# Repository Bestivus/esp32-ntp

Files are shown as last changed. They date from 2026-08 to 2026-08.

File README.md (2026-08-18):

## About this fork

This is a fork of [dniminenn/esp32-ntp](https://github.com/dniminenn/esp32-ntp) - a genuinely
excellent piece of engineering, and huge thanks to dniminenn for open-sourcing it. Everything below
this section is the upstream project as-is; here's what changed while bringing it up on my own
hardware.

An earlier version of this fork carried its own ESP-IDF v6.0.2 build fixes and two Kconfig bug
fixes (timezone, display), submitted upstream as PRs. Upstream has since landed its own rewrite -
a first-party W5500 driver replacing the vendored `ioLibrary_Driver`, and an NVS-backed settings
system replacing direct Kconfig reads - which fixes both of those problems natively and makes the
old patches moot. This branch is rebased onto that current upstream code rather than carrying
now-obsolete fixes forward.

- **Dropped the forked `ioLibrary_Driver` submodule.** This fork previously carried a patched
  submodule solely to fix a `recv()` bug where the non-blocking-mode check fired before the
  data-available check, so a non-blocking TCP socket could never actually read data. Upstream's
  new `w5500_drv` fixes this natively, so the fork and the patch are both gone.
- **3D-printed enclosure** ([PR #3](https://github.com/dniminenn/esp32-ntp/pull/3), see
  [`hardware/enclosure/`](hardware/enclosure/)): a two-piece, magnet-held case sized for this
  exact build (D1 Mini ESP32 + W5500 + SparkFun MAX-M10S GPS), STEP and STL included.
- **MQTT status publishing with Home Assistant discovery** (`components/mqtt_publish/`, kept in
  this fork only): publishes GPS lock, stratum, offset, jitter, and diagnostics to an MQTT broker
  with HA auto-discovery. Re-implemented from scratch as a hand-rolled, zero-dependency MQTT 3.1.1
  wire codec running on upstream's `w5500_drv`, since the previous implementation leaned on
  Paho MQTT-C code pulled from the now-dropped `ioLibrary_Driver`. Still a non-blocking,
  tick-driven state machine polled from the NTP task's housekeeping slot, at most one socket call
  per tick, so it can never delay a PPS capture or an NTP reply.
- **`sdkconfig.defaults`** instead of a committed full `sdkconfig`: lists this fork's build-time
  differences from upstream's defaults individually (no display attached, `-O2` build, the
  FreeRTOS tick-rate fix), rather than a full local config snapshot that would carry this
  machine's network settings and credentials into the repo.

The full technical write-up for the original v6.0.2 migration - root causes, debugging process,
everything found and fixed on the code this fork has since moved on from - is in
[`CLAUDE.md`](CLAUDE.md), kept as history.

---

# esp32-ntp: a GPS-disciplined Stratum 1 NTP server for the ESP32

**Writeup:** [Building a GPS stratum 1 NTP server on an ESP32](https://dnim.dev/blog/esp32-stratum-1-ntp)

An ESP32 plus a cheap GPS module, serving Stratum 1 NTP over Ethernet (WIZnet W5500) or
Wi-Fi. PPS edges are captured by the MCPWM peripheral in silicon and packet arrival is
timestamped off the W5500 interrupt, so neither the discipline nor the served timestamps
depend on when a poll loop noticed.

Configuration lives in flash and is edited from a page the device serves itself, so a
deployed clock needs no rebuild and no serial cable. See [Configuration](#configuration).

## What it does

- **Stratum 1 from GPS + PPS.** No internet or upstream server once the GPS has a fix.
- **Hardware timestamping both ways.** MCPWM capture for PPS (12.5 ns resolution at
  80 MHz), W5500 `INTn` capture for NTP arrival.
- **Interleaved mode (RFC 9769).** Clients that ask for it get the measured transmit time
  of the previous reply rather than a predicted one. Invisible to clients that do not.
- **Ethernet or Wi-Fi**, switchable at runtime. The Wi-Fi path compiles out on parts with
  no radio.
- **Settings in flash, edited from a browser**, with a permanent lock for deployment and a
  recovery path if a setting locks you out.
- **Prometheus metrics** at `GET /metrics`.
- **Self-healing:** task watchdog reboots on a hang, and a W5500 health check restarts the
  device if the network chip wedges.
- **Optional MAX7219 LED display.**

## Accuracy

Measured against independent GPS references on the same LAN. Two figures matter and they
are different things:

| | |
|---|---|
| Internal discipline (against its own PPS) | single-digit ns offset, 7 to 11 ns PPS jitter |
| Served time (what a client actually sees) | tens of us, dominated by the network path |

The gap between those two is not the clock. It is the W5500 at 100 Mbit and whatever sits
between the board and the client. A gigabit observer one switch away measured this
firmware at -11.2 us before calibration and within about 100 ns after, with roughly 3 us of
that figure attributable to the 100 Mbit to gigabit speed transition rather than to the
board.

Independent cross-checks: an Intel i210 plus NEO-M9N PTP grandmaster, measuring the ESP32
one routed hop away with its own NIC hardware timestamping, saw about 60 us of offset and
10 to 25 us of per-sample jitter. Separately, in a four-clock ensemble (two NIC-PHC clocks,
a BeagleBone PRU clock and this ESP32), three chrony observers each running full source
selection accept the ESP32 as a truechimer against the other three.

Your numbers depend on your GPS, your antenna, your wiring and your network. The limit is
almost always one of those rather than the ESP32.

## Hardware

<p align="center">
  ESP32 stratum-1 NTP signal wiring: u-blox NEO-6M GPS (NMEA over UART, PPS into GPIO19 captured by MCPWM), and the WIZnet W5500 over SPI with INTn on GPIO34 for hardware RX timestamping. The two hardware-timestamped nets, PPS and INTn, are in coral.
</p>

- **MCU:** the original ESP32 (IDF target `esp32`). 2 MB of flash is enough; the app partition is
  1.9 MB and about half free.

  Three SoC capabilities decide whether a part in the family can run this at all. **MCPWM**, because
  the PPS edge is latched by the capture submodule (capture is not separately gated: ESP-IDF builds
  `mcpwm_cap.c` on `SOC_MCPWM_SUPPORTED` alone, and the capture registers are present in every
  MCPWM-bearing target). **Two usable SPI hosts**, because SPI1 is tied to flash and the W5500 and
  the display each need their own bus, so `SOC_SPI_PERIPH_NUM` has to be 3. WiFi is **not** a
  requirement: the WiFi path compiles itself out on parts without a radio, so those still build and
  simply have no WiFi option. Checked against `soc_caps.h` in ESP-IDF v6.0.2:

  | Target | MCPWM | Usable SPI | WiFi | Verdict |
  |---|---|---|---|---|
  | **ESP32** | yes | 2 | yes | **Supported. The only part built and measured.** |
  | **ESP32-S3** | yes | 2 | yes | **Meets every requirement. Never built here.** |
  | ESP32-C5 | yes | 1 | yes | Only without the display, one bus for the W5500 |
  | ESP32-C6 | yes | 1 | yes | Only without the display, one bus for the W5500 |
  | ESP32-S2 | no | 2 | yes | Impossible, no MCPWM |
  | ESP32-C2 | no | 1 | yes | Impossible, no MCPWM |
  | ESP32-C3 | no | 1 | yes | Impossible, no MCPWM |
  | ESP32-C61 | no | 1 | yes | Impossible, no MCPWM |
  | ESP32-H4 | yes | 2 | no | Builds, Ethernet only, no WiFi option |
  | ESP32-P4 | yes | 2 | no | Builds, but do not: see below |
  | ESP32-H2 | yes | 1 | no | Ethernet only, and no bus left for the display |
  | ESP32-H21 | yes | 1 | no | Ethernet only, and no bus left for the display |

  The four "impossible" rows have no MCPWM and no path forward. Everything else builds from the same
  source with no configuration change; dropping the WiFi path saves about 488 KB of flash where it
  is not available. Anything other than the ESP32 also needs the pin map revisited, which assumes
  ESP32 GPIO numbering and its input-only 34 to 39, and none of them have been built or measured
  here.

  **The ESP32-P4 is a special case: it builds, and you should not.** It is the one part in the
  family whose Ethernet MAC does IEEE 1588v2 hardware timestamping
  (`SOC_EMAC_IEEE1588V2_SUPPORTED`), so the packet timestamps this project works so hard to
  approximate with a W5500 and an interrupt edge are simply available in silicon. Bolting an SPI NIC
  onto a P4 would be strictly worse than using its own MAC, and it is a far more expensive part.
  That gap is also the reason the W5500 exists here at all: the original ESP32 has an EMAC, but
  without 1588 support, so an external MAC whose `INTn` marks arrival is the closest thing to a
  hardware receive timestamp this silicon can offer.
- **Toolchain:** ESP-IDF **v6.0**. Earlier versions predate the split driver components
  (`esp_driver_gpio`, `esp_driver_uart`, `esp_driver_spi`, `esp_driver_mcpwm`) that this project
  requires, so they fail at configure time rather than building something subtly wrong. CI builds
  v6.0.2 from a clean clone.
- **Crystal:** the build pins 40 MHz (`CONFIG_XTAL_FREQ`); some modules ship with a 26 MHz crystal
  instead, and the tell is garbage on the serial console at 115200. If that's your board, change
  `CONFIG_XTAL_FREQ` in `menuconfig`.
- **GPS:** any UART NMEA module with a PPS output (for example NEO-6M, NEO-M8N, or NEO-M9N). PPS
  goes to any GPIO, including input-only pins 34 to 39, because it's captured by the MCPWM
  peripheral.
- **Ethernet (recommended):** WIZnet W5500 on its own SPI bus (HSPI / SPI2 by default, 20 MHz). Its
  `INTn` pin is wired to a GPIO (default GPIO34) for hardware RX timestamping.
- **Display (optional):** up to 4x MAX7219 8x8 matrices on a separate SPI bus (VSPI / SPI3).

Default pins live in `components/config/config.cpp` and can be overridden in `menuconfig`.

## Bill of materials

Street prices for the clone-grade parts most people actually buy (AliExpress / HiLetgo tier, 2026).

| Part | Role | Typical price |
| --- | --- | --- |
| ESP32 DevKitC / WROOM-32 dev board | MCU, MCPWM capture, servo | $5 |
| NEO-6M GPS module + ceramic antenna | GPS fix and the PPS edge | $6 |
| WIZnet W5500 module (RJ45 + magnetics) | wired Ethernet, hardware timestamping | $7 |
| Jumper wires / small perfboard | wiring | $2 |
| 5V USB supply | power (you probably already own one) | $0 to $3 |
| MAX7219 4-in-1 8x8 matrix (optional) | LED display | $6 |

The MCU row means the original ESP32 specifically. See **Hardware** above for which parts in the
family can and cannot run this, and why.

That is about **$20 for the Ethernet Stratum 1**, or roughly **$26 with the display**. The NEO-6M is
the cheapest module with a PPS pin, which is what makes the $20 number real. A NEO-M8N (around $15)
or NEO-M9N (around $30) tightens the PPS and the fix if you want the best version, pushing the build
to roughly $30 to $45.

For comparison, the usual Raspberry Pi Stratum 1 (Pi plus a GPS HAT plus an SD card) lands around
$90 to $130 and still takes its timestamps in software, so it carries Linux scheduling jitter.
Hobby appliances like LeoNTP run about $300, and commercial GPS Stratum 1 units run from $200 into
the thousands.

What makes this build worth its salt rather than just cheap is the part that costs nothing: the
hardware timestamping. MCPWM capture on the PPS edge, W5500 interrupt capture on packet arrival, and
the transmit correction are what put the served jitter under a microsecond, where a naive $20 build
would sit in the milliseconds.

## Build and flash

Prerequisites:
- ESP-IDF v6.0 installed, with `IDF_PATH` set. CI builds v6.0.2; earlier versions do not have the
  split driver components this project requires.

```bash
make build          # idf.py build
make flash          # flash firmware (override speed with: make flash BAUD=230400)
make monitor        # open the serial console
make flash-monitor  # flash then monitor
make menuconfig      # open project configuration
```

Or call `idf.py` directly if you prefer.

> **Tip:** if `make flash` drops mid-transfer ("chip stopped responding") on a flaky USB-serial
> bridge, lower the baud: `make flash BAUD=230400`.

## Configuration

Settings live in flash and are edited from the device's own web page. Everything below can also be
set at build time in `menuconfig`, and those build-time values are what an unconfigured device runs
on, so a freshly flashed board comes up exactly as it always did.

### Settings page

Point a browser at the device on the management port (`8080` by default):

```
http://<device-ip>:8080/
```

Everyday settings are on the page directly: network interface, DHCP or a static address, timezone
(a dropdown of common zones, not a raw POSIX string), the display toggles, the management port, and
an optional password. Wiring settings (every GPIO, SPI host, SPI clock, the GPS UART and the PPS
pin) sit behind an **Advanced** disclosure, because a wrong pin there takes the clock off the
network on the next restart.

Saving writes only the fields you changed and reboots. Values are validated before anything reaches
flash, so an out-of-range pin or a malformed IP is refused with nothing written. Fields marked `*`
need the restart to take effect.

Set a password under **System** unless the network is fully trusted: without one, anyone who can
reach the address can reconfigure or reboot the clock. `/metrics` stays unauthenticated either way
so Prometheus can scrape it.

### Locking it down

Once a clock is configured and in service, the settings page is pure attack surface. Two controls,
in increasing severity:

**Password.** Set one under **System**. It applies to the settings page only; `/metrics` stays open
so Prometheus can scrape without credentials.

**Lock settings permanently.** A fuse. Saving it removes the settings page, `GET /` and
`/config` and `POST /config` all answer `403`, and so does `/factory-reset`, because a reset that
cleared the lock would not be a lock. What survives is NTP on port 123 and `/metrics`, which is
everything a deployed clock actually needs.

It is one way. Nothing over the network undoes it, and neither does the safe-mode path below: safe
mode reads the lock straight out of NVS rather than from the settings it is ignoring, so a bad
config still recovers while the page stays shut. The only way back is physical, erasing the NVS
partition over USB:

```bash
esptool --port /dev/ttyUSB0 erase-region 0x9000 0x6000
```

That takes every stored setting with it and the device returns to build-time defaults.

Locking needs a password set first, which only stops you doing it by accident. Anyone who can
reach an unprotected page owns the device, fuse included.

### If a setting makes the device unreachable

Interrupt startup twice, with the reset button or the power lead. The third boot ignores stored
settings and comes up on the build-time defaults, with a banner on the settings page explaining
why. Your stored values are still in flash and are not touched; saving from that page overwrites
them, and any restart that reaches the network clears the condition on its own.

**Erase stored settings** at the bottom of the page wipes everything back to build-time defaults.

### Settings reference

Every runtime setting, generated from the single table in
`components/config/config_store.c`. **R** means the change takes effect on restart,
**A** means it sits behind the Advanced disclosure on the settings page.

#### Network

| Key | Type | Range | Flags | Setting |
|---|---|---|---|---|
| `net.mode` | choice | `wiznet` / `wifi` | R | Interface. `wifi` is absent on parts with no radio. |
| `net.dhcp` | bool | 0 / 1 | R | Use DHCP. Off means the three fields below are used. |
| `net.ip` | text |  | R | Static IP |
| `net.gw` | text |  | R | Gateway |
| `net.mask` | text |  | R | Netmask |
| `wifi.ssid` | text |  | R | WiFi SSID. Only used when the interface is WiFi. |
| `wifi.pass` | password |  | R | WiFi password |

#### System

| Key | Type | Range | Flags | Setting |
|---|---|---|---|---|
| `sys.tz` | text |  |  | Timezone. Affects the LED display only. NTP always serves UTC. |
| `stats.port` | int | `1`..`65535` | R | Management port. This page and /metrics. |
| `ui.pass` | password |  |  | Management password. Blank leaves this page open to anyone on the network. |
| `ui.lock` | bool | 0 / 1 |  | Lock settings permanently. One way. Saving this removes the settings page for good; only erasing  |

#### Display

| Key | Type | Range | Flags | Setting |
|---|---|---|---|---|
| `disp.en` | bool | 0 / 1 | R | Enable display |
| `disp.glyph` | bool | 0 / 1 |  | Show presync glyph. Marker shown until the GPS locks. |

#### Service

| Key | Type | Range | Flags | Setting |
|---|---|---|---|---|
| `ntp.port` | int | `1`..`65535` | R A | NTP port. 123 is the standard. Clients will not find it anywhere else. |
| `serve.cal` | int | `-100000`..`100000` | A | Serve calibration (us). Subtracted from t2 and t3. Re-derive before changing. |

#### Display wiring

| Key | Type | Range | Flags | Setting |
|---|---|---|---|---|
| `disp.host` | int | `1`..`2` | R A | SPI host. 1 = SPI2, 2 = SPI3. Must differ from the W5500 host. |
| `disp.cs` | int | `-1`..`33` | R A | CS pin |
| `disp.mosi` | int | `-1`..`33` | R A | MOSI pin |
| `disp.sclk` | int | `-1`..`33` | R A | SCLK pin |
| `disp.hz` | int | `100000`..`20000000` | R A | SPI clock (Hz) |
| `disp.ndev` | int | `1`..`16` | R A | Cascaded modules |

#### W5500 wiring

| Key | Type | Range | Flags | Setting |
|---|---|---|---|---|
| `w5.host` | int | `1`..`2` | R A | SPI host. 1 = SPI2, 2 = SPI3. Must differ from the display host. |
| `w5.cs` | int | `-1`..`33` | R A | CS pin |
| `w5.mosi` | int | `-1`..`33` | R A | MOSI pin |
| `w5.miso` | int | `-1`..`39` | R A | MISO pin |
| `w5.sclk` | int | `-1`..`33` | R A | SCLK pin |
| `w5.int` | int | `-1`..`39` | R A | INT pin. Hardware RX timestamping depends on this. |
| `w5.rst` | int | `-1`..`33` | R A | RST pin |
| `w5.hz` | int | `1000000`..`20000000` | R A | SPI clock (Hz). 20 MHz is the proven ceiling on GPIO-matrix pins. Reads corrupt silently above it. |

#### GPS wiring

| Key | Type | Range | Flags | Setting |
|---|---|---|---|---|
| `gps.uart` | int | `0`..`2` | R A | UART port |
| `gps.rx` | int | `-1`..`39` | R A | RX pin (GPS TX) |
| `gps.tx` | int | `-1`..`33` | R A | TX pin |
| `gps.baud` | int | `1200`..`921600` | R A | Baud rate |
| `pps.gpio` | int | `-1`..`39` | R A | PPS pin. Hardware-captured by MCPWM. The whole clock rides on this. |
| `pps.cal` | int | `-1000000`..`1000000` | A | PPS calibration (us) |

`net.mode` is a choice between the W5500 Ethernet path and Wi-Fi STA. `pps.cal` and
`serve.cal` are microsecond trims: `pps.cal` shifts the PPS reference, `serve.cal` is
subtracted from both `t2` and `t3` on the way out. Both default to a value measured on the
reference wiring, so re-derive them if yours differs.

Adding a setting means adding one row to that table. The settings page renders and parses
itself from it, so there is no second place to update.

### Build-time defaults

Project options live under **`esp32-ntp configuration`** in `menuconfig`:

- **Network**
  - **Network interface:** WIZnet W5500 Ethernet or Wi-Fi STA. IP works the same either way
    (DHCP by default, or static IP/gateway/netmask). Hardware transmit-timing correction is used on
    the W5500 path; Wi-Fi uses the same GPS/PPS discipline over the lwIP stack.
  - **Wi-Fi STA:** set **SSID** and **password**.
- **NTP / timezone**
  - `APP_TZ`: POSIX timezone string. Examples:
    - Eastern US: `EST5EDT,M3.2.0,M11.1.0`
    - Central Europe: `CET-1CEST,M3.5.0,M10.5.0/3`
    - UK: `GMT0BST,M3.5.0/1,M10.5.0/2`
    - Atlantic Canada: `AST4ADT,M3.2.0,M11.1.0`
- **SPI / Display**
  - `APP_USE_DISPLAY` and the MAX7219 SPI host/pinout (`APP_SPI_HOST`, `APP_SPI_MOSI_PIN`,
    `APP_SPI_SCLK_PIN`, `APP_CS_PIN`, `APP_MAX_DEVICES`, `APP_SPI_CLOCK_HZ`).

The full set of runtime settings, their valid ranges and their build-time defaults are declared in
one table in `components/config/config_store.c`; adding a setting means adding a row there, and the
settings page renders and parses itself from it.

## Runtime behavior

On boot, `app_main` initializes NVS, brings up the selected network interface (W5500 or Wi-Fi) with
DHCP or static IP, applies the timezone, optionally starts the display task, and then starts GPS/PPS
disciplining, the NTP server, and the stats HTTP server.

**DHCP** on the W5500 path caches the bound lease in flash and reclaims it on the next start
(RFC 2131 INIT-REBOOT) rather than rediscovering from scratch. The address is programmed before the
server confirms it, so a restart while the DHCP server is unreachable still comes back on the last
known-good address instead of a fallback; a NAK hands it straight back and triggers a full
discovery. Only the address, gateway, netmask and server identity are cached, and only rewritten
when those change, so renewals never touch flash. Time from link-up to a usable address is about a
second, since the first frame after link-up is routinely lost while the switch port settles and the
retry backs off 1 s, 2 s, then 4 s rather than waiting 4 s to notice.

**NTP server** (UDP port 123):
- Synthesizes NTP timestamps from the last PPS edge plus a frequency-corrected monotonic timer.
- On the W5500 path: timestamps the request on arrival via the `INTn` interrupt, resolves ARP up
  front, then sends a single reply whose transmit timestamp is pre-corrected for send latency.
- On the Wi-Fi path: a single send through the ESP-IDF lwIP stack.

**Stats / diagnostics HTTP server** (`GET /metrics` on TCP port 8080), Prometheus text format:

| Metric | Meaning |
| --- | --- |
| `ntp_clock_offset_seconds` | Last measured clock offset |
| `ntp_rms_offset_seconds` | Exponentially weighted RMS offset |
| `ntp_frequency_ppm` | Estimated oscillator frequency error |
| `ntp_pps_jitter_seconds` | PPS pulse jitter |
| `ntp_root_dispersion_seconds` | Estimated root dispersion |
| `ntp_gps_lock` | GPS lock state (1 = locked) |
| `ntp_stratum` | NTP stratum (1 when locked) |
| `ntp_uptime_seconds` | Seconds since boot |
| `ntp_requests_total` | NTP requests served |
| `ntp_pps_count` | PPS edges received |
| `ntp_pps_rejects_total` | PPS pulses rejected as outliers |
| `ntp_rx_irq_total` | W5500 RX interrupts captured (hardware arrival edges) |
| `ntp_tx_correction_us` | Self-calibrated transmit-path correction added to `t3` (basic mode only) |
| `ntp_interleaved_served_total` | Replies answered in interleaved mode (RFC 9769) |
| `ntp_reset_reason` | `esp_reset_reason()` of the last boot (1=power-on, 7=task WDT, 8=int WDT, 9=brownout) |
| `ntp_boot_count` | Boots since flash (NVS-persisted, so a jump means it auto-recovered) |
| `ntp_main_loop_beats` | Core-0 main-loop heartbeat |
| `ntp_free_heap_bytes` / `ntp_min_free_heap_bytes` | Current / lowest-ever free heap |
| `ntp_eth_link_up` | W5500 link health |
| `ntp_w5500_version` | W5500 `VERSIONR` (4 = healthy) |

**Self-recovery:** the task watchdog is set to reboot, not just warn, so a firmware hang restarts
the device within seconds. Separately, a W5500 health check restarts the device if the Ethernet chip
or link stays unresponsive. Both are visible after the fact via `ntp_boot_count` and
`ntp_reset_reason`, so you can diagnose a field fault by curling `/metrics` instead of attaching a
cable.

## Code structure

- `main/app_main.cpp`: system bring-up, component wiring, main loop, liveness/boot diagnostics.
- `components/config`: pinout and configuration accessors (`Config::...`).
- `components/gps`: NMEA parsing and PPS discipline (MCPWM hardware capture, PI servo, outlier
  rejection).
- `components/ntp_server`: NTP server over W5500 UDP or Wi-Fi UDP, with hardware RX timestamping and
  transmit-timestamp correction.
- `components/webui`: the HTTP server the device runs on itself. `web_server.cpp` is transport,
  request assembly, routing and auth; `web_metrics.cpp` renders `/metrics`; `web_config.cpp`
  renders and parses the settings page.
- `components/w5500_eth`: W5500 SPI driver, DHCP/static IP, PHY setup, and the link/health watchdog.
- `components/wifi_sta`: Wi-Fi STA with DHCP or static IP.
- `components/w5k`: latency-tuned UDP/TCP wrappers over the W5500 driver for the NTP reply path.
- `components/display`: MAX7219 display driver and rendering.

## License

All code in this repository is released into the public domain under **The Unlicense**, see `LICENSE`.

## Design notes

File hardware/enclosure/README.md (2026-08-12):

# Enclosure

3D-printed two-piece case (magnet-held lid) sized for the "D1 Mini ESP32" board (ESP32-WROOM-32
module, no mounting holes), the W5500 Ethernet breakout, and the SparkFun MAX-M10S GPS module, as
wired up in this project.

Designed in Fusion 360 (Personal), sliced/printed with Orca Slicer.

## Files

- `bottom-case.step` / `bottom-case.stl`
- `top-lid.step` / `top-lid.stl`

`.step` is the editable source (open in any CAD tool to modify); `.stl` is the print-ready mesh.

## Mounting hardware

- **ESP32**: no screws -- held by a friction-fit cradle.
- **GPS module**: 4x M3x6 button head screws.
- **W5500 breakout**: 2x M3x6 button head screws, plus a rear clip molded into the case.

## Magnets

Each half has four embedded holes for 6x2mm magnets (6mm diameter, 2mm thick; eight magnets
total), used to hold the lid closed:

- **Bottom case**: hole diameter 6.2mm, depth 2.4mm, 0.6mm of material remaining above the
  magnet cutout.
- **Top lid**: hole diameter 6.2mm, depth 2.4mm, 0.5mm of material remaining between the lid
  surface and the magnet cutout.

The magnets are embedded during printing, not press-fit afterward: when slicing, insert a pause
in the g-code at the layer where each cutout closes off, drop the magnet in, then resume -- the
print continues over the top of it. Check your slicer's docs for how to add a pause-at-layer/
pause-at-height correctly. Tested on a Bambu Lab X2D without issues, but your mileage may vary --
verify the pause height, the magnet fit tolerance, and consider a non-magnetic nozzle before
committing to a full print.

## License

Unlicense (public domain), matching the rest of this project.

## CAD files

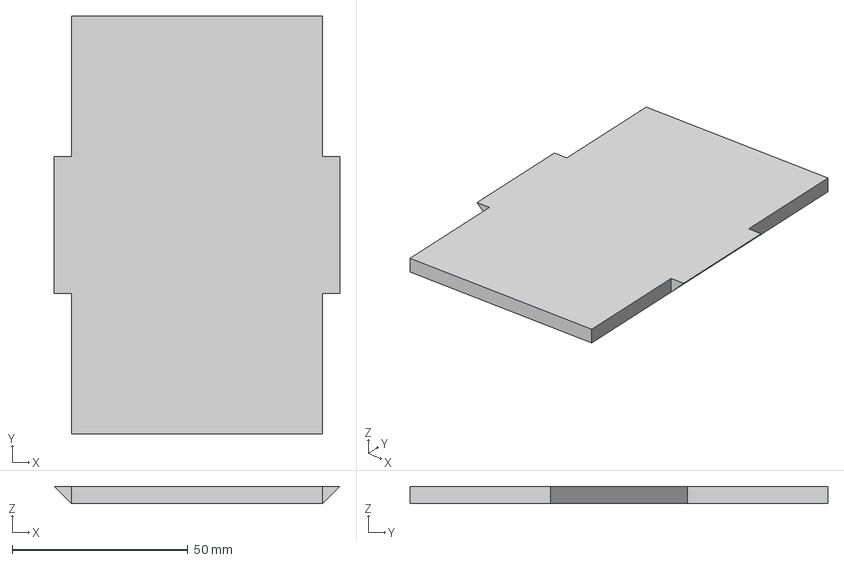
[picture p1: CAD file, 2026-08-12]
hardware/enclosure/top-lid.step
81.3 x 119.0 x 4.90 mm

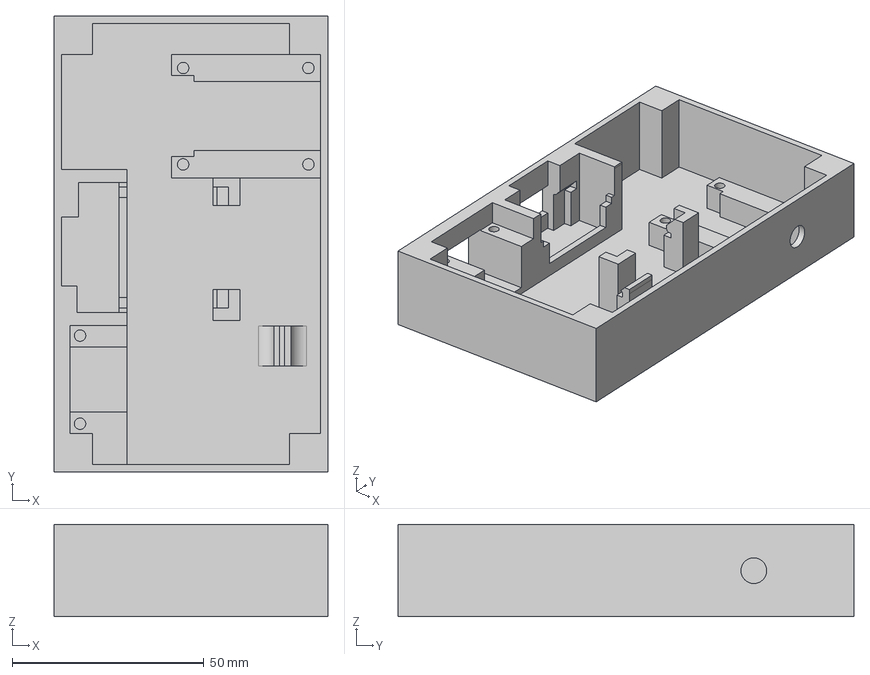
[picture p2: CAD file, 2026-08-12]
hardware/enclosure/bottom-case.step
71.5 x 119.0 x 24.1 mm

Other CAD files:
hardware/enclosure/bottom-case.stl
hardware/enclosure/top-lid.stl

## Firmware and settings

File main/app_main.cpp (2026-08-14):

// SPDX-License-Identifier: Unlicense
// main/app_main.cpp

#include <string.h>
#include <sys/time.h>
#include <time.h>
#include "freertos/FreeRTOS.h"
#include "freertos/task.h"
#include "freertos/semphr.h"
#include "esp_event.h"
#include "esp_log.h"
#include "esp_timer.h"
#include "nvs_flash.h"
#include "nvs.h"
#include "esp_system.h"
#include "esp_netif.h"
#include "driver/uart.h"
#include "esp_pm.h"

#include "config.h"
#include "config_store.h"
#include "display.h"
#include "gps.h"
#include "esp_task_wdt.h"
#include "ntp_server.h"
#include "web_server.h"
#include "w5500_eth.h"
#include "wifi_sta.h"
#include "mqtt_publish.h"

static const char* TAG = "APP";

static Display* g_display = nullptr;
static GpsDiscipline* g_gps = nullptr;
static NtpServer* g_ntpServer = nullptr;
static WebServer* g_web = nullptr;
static W5500Eth* g_ethernet = nullptr;
static WifiSta* g_wifi = nullptr;
static MqttPublisher* g_mqtt = nullptr;
static SemaphoreHandle_t g_displayMutex = nullptr;

// Diagnostics exposed over /metrics (read-only; never on the timekeeping path).
// g_mainLoopBeats advances every core-0 loop iteration — if it stalls between
// two HTTP scrapes the loop is wedged; g_bootCount (persisted in NVS) counts
// boots, so an auto-recovery (watchdog reboot / W5500 restart) is visible
// remotely without attaching a serial monitor.
volatile uint32_t g_mainLoopBeats = 0;
uint32_t g_bootCount = 0;

extern "C" void app_main();

static void display_task(void* arg) {
  int lastDisplayedSecond = -1;
  unsigned long long lastCentiseconds = 0;
  bool wasSynced = false;
  bool glyphShown = false;

  ESP_LOGI(TAG, "Display task started");

  while (true) {
    if (xSemaphoreTake(g_displayMutex, pdMS_TO_TICKS(10))) {
      struct timeval tv;
      gettimeofday(&tv, nullptr);
      struct tm timeinfo;
      localtime_r(&tv.tv_sec, &timeinfo);
      
      unsigned long long centiseconds = (unsigned long long)(esp_timer_get_time() / 10000ULL);
      
      if (centiseconds != lastCentiseconds) {
        int currentSecond = timeinfo.tm_sec;
        bool synced = (g_gps && g_gps->isLocked());
        if (synced && !wasSynced) {
          g_display->clear();
          lastDisplayedSecond = -1;
        }
        
        if (!synced) {
          if (!glyphShown) {   /* static image; redraw only on entering the unsynced state */
            g_display->clear();
            g_display->drawPreSyncGlyph();
            g_display->push();
            glyphShown = true;
          }
        } else {
          glyphShown = false;
          if (currentSecond != lastDisplayedSecond) {
            ESP_LOGD(TAG, "Update display: %02d:%02d:%02d", timeinfo.tm_hour, timeinfo.tm_min, timeinfo.tm_sec);
            g_display->drawTime(timeinfo.tm_hour, timeinfo.tm_min, timeinfo.tm_sec);
            lastDisplayedSecond = currentSecond;
          }
          g_display->drawTopRowFromCentiseconds(centiseconds);
          g_display->push();
        }
        lastCentiseconds = centiseconds;
        wasSynced = synced;
      }
      
      xSemaphoreGive(g_displayMutex);
    }
    vTaskDelay(pdMS_TO_TICKS(1));
  }
}

/* --- Task layout ------------------------------------------------------ */
/* Discipline must outrank serving: a packet flood must never delay a pulse. */
#define PRIO_DISCIPLINE 10
#define PRIO_NTP         7
#define CORE_CLOCK       0
#define CORE_NET         1

static void discipline_task(void* arg) {
  esp_task_wdt_add(nullptr);
  gps_register_task(xTaskGetCurrentTaskHandle());
  for (;;) {
    g_mainLoopBeats = g_mainLoopBeats + 1;              /* liveness, exported over /metrics */
    /*
     * Wake on the PPS capture edge instead of polling for it. The 50 ms timeout
     * is a safety net, not the mechanism: it keeps the holdover checks in
     * GpsDiscipline::loop() running when PPS stops, which is precisely when they
     * matter. NMEA is not affected — it has its own gps_uart task.
     *
     * Note this makes g_mainLoopBeats advance ~20x/s instead of ~500x/s. It is a
     * liveness heartbeat, so what matters is that it still advances.
     */
    gps_wait_for_pps(50);
    if (g_gps) g_gps->loop();
    esp_task_wdt_reset();
  }
}

static void ntp_task(void* arg) {
  esp_task_wdt_add(nullptr);
  unsigned long lastLog = 0;
  unsigned long lastHouse = 0;
  for (;;) {
    /*
     * Wake on the W5500's INTn interrupt. The timeout is a safety net only:
     * a second datagram queued behind one INTn assertion produces no new edge,
     * so a periodic sweep still drains it.
     */
    ntp_wait_for_packet(5 /* ms */);
    if (g_ntpServer) g_ntpServer->loop();

    /*
     * Housekeeping shares this task deliberately. Every W5500 access funnels
     * through shared static frame buffers with no locking anywhere in the
     * driver (w5500_drv.c relies on this), so a second task touching the chip
     * corrupts transfers in flight. Serving from here keeps a single owner
     * without a mutex the hot path would have to acquire per packet.
     */
    /* Time-gated, not sweep-counted: under a burst, packet rate must not drag
     * housekeeping SPI into the reply path. */
    unsigned long nowMs = (unsigned long)(esp_timer_get_time() / 1000ULL);
    if (nowMs - lastHouse >= 20) {
      lastHouse = nowMs;
      if (g_ethernet) g_ethernet->loop();
#if CONFIG_SOC_WIFI_SUPPORTED
      if (g_wifi) g_wifi->loop();
#endif
      if (g_web) g_web->loop();
      if (g_mqtt) g_mqtt->loop();
      unsigned long now = esp_timer_get_time() / 1000000ULL;
      if (now - lastLog >= 60) {
        struct timeval tv2; struct tm ti2;
        gettimeofday(&tv2, nullptr);
        localtime_r(&tv2.tv_sec, &ti2);
        ESP_LOGI(TAG, "Current time: %02d:%02d:%02d", ti2.tm_hour, ti2.tm_min, ti2.tm_sec);
        lastLog = now;
      }
    }
    esp_task_wdt_reset();
  }
}

void app_main() {
  uart_wait_tx_done(static_cast<uart_port_t>(CONFIG_ESP_CONSOLE_UART_NUM), pdMS_TO_TICKS(100));
  vTaskDelay(pdMS_TO_TICKS(500));
  
  uart_flush_input(static_cast<uart_port_t>(CONFIG_ESP_CONSOLE_UART_NUM));
  
  printf("\n\n\n");
  printf("========================================\n");
  printf("       esp32-ntp v1.0\n");
  printf("========================================\n\n");
  
  esp_log_level_set("*", ESP_LOG_INFO);
  esp_log_level_set(TAG, ESP_LOG_INFO);
  esp_log_level_set("spi_master", ESP_LOG_WARN);

  ESP_LOGI(TAG, "=== Clock Starting ===");
  ESP_LOGI(TAG, "Initializing NVS...");
  ESP_ERROR_CHECK(nvs_flash_init());

  // Persisted boot counter — a jump between scrapes reveals an auto-recovery
  // (watchdog reboot or W5500 restart) without needing a serial console.
  {
    nvs_handle_t h;
    if (nvs_open("diag", NVS_READWRITE, &h) == ESP_OK) {
      nvs_get_u32(h, "boots", &g_bootCount);
      g_bootCount++;
      nvs_set_u32(h, "boots", g_bootCount);
      nvs_commit(h);
      nvs_close(h);
    }
    ESP_LOGI(TAG, "Boot count: %u, reset reason: %d", (unsigned)g_bootCount, (int)esp_reset_reason());
  }

  {
    uint8_t attempt = cfg_boot_begin();
    bool safeMode = attempt >= CFG_SAFE_MODE_FAILS;
    ESP_LOGI(TAG, "Start attempt %u since the last start that reached the network",
             (unsigned)attempt);
    Config::init(safeMode);
    if (safeMode) {
      ESP_LOGE(TAG, "SAFE MODE on start attempt %u: build-time defaults, "
                    "stored settings ignored until you save from the config page",
               (unsigned)attempt);
    } else if (cfg_locked()) {
      ESP_LOGW(TAG, "Settings are locked; the config page is disabled");
    } else if (Config::isProvisioned()) {
      ESP_LOGI(TAG, "Using stored settings from NVS");
    } else {
      ESP_LOGI(TAG, "No stored settings, using build-time defaults");
    }
  }

  // Set a reasonable initial time to avoid massive NTP corrections
  struct timeval tv;
  gettimeofday(&tv, nullptr);
  ESP_LOGI(TAG, "Initial system time: %ld seconds (epoch: %ld)", tv.tv_sec, tv.tv_sec);
  
  if (tv.tv_sec < 1577836800LL) {  // Before 2020-01-01
    tv.tv_sec = 1700000000LL;  // Set to 2023-11-15 as reasonable default
    tv.tv_usec = 0;
    settimeofday(&tv, nullptr);
    ESP_LOGI(TAG, "Set initial time to 2023-11-15 to avoid massive NTP corrections");
    
    // Verify the change
    gettimeofday(&tv, nullptr);
    ESP_LOGI(TAG, "New system time: %ld seconds", tv.tv_sec);
  } else {
    ESP_LOGI(TAG, "System time already reasonable: %ld seconds", tv.tv_sec);
  }
  
  // Initialize networking infrastructure first
  ESP_ERROR_CHECK(esp_netif_init());
  ESP_ERROR_CHECK(esp_event_loop_create_default());
  
  esp_err_t err;

  if (Config::getNetworkWiznet()) {
    ESP_LOGI(TAG, "Initializing W5500 Ethernet...");
    g_ethernet = new W5500Eth();
    err = g_ethernet->begin(
      Config::getW5500SpiHost(),
      Config::getW5500MosiPin(),
      Config::getW5500MisoPin(),
      Config::getW5500SclkPin(),
      Config::getW5500CsPin(),
      Config::getW5500IntPin(),
      Config::getW5500RstPin(),
      Config::getW5500SpiHz()  // 20 MHz default; W5500 spec allows far more
    );
    if (err == ESP_OK) {
      ESP_LOGI(TAG, "W5500 initialized, starting Ethernet...");
      g_ethernet->start(Config::getUseStaticIp(), Config::getStaticIp(),
                       Config::getStaticGw(), Config::getStaticNetmask());
    } else {
      ESP_LOGE(TAG, "W5500 initialization failed: %s", esp_err_to_name(err));
      delete g_ethernet;
      g_ethernet = nullptr;
    }
#if CONFIG_SOC_WIFI_SUPPORTED
  } else if (Config::getNetworkWifi()) {
    ESP_LOGI(TAG, "Initializing WiFi STA...");
    g_wifi = new WifiSta();
    err = g_wifi->begin(Config::getWifiSsid(), Config::getWifiPassword(),
                        Config::getUseStaticIp(), Config::getStaticIp(),
                        Config::getStaticGw(), Config::getStaticNetmask());
    if (err == ESP_OK) {
      g_wifi->start();
      ESP_LOGI(TAG, "WiFi STA started, connecting...");
    } else {
      ESP_LOGE(TAG, "WiFi begin failed: %s", esp_err_to_name(err));
      delete g_wifi;
      g_wifi = nullptr;
    }
#endif
  }
  
  ESP_LOGI(TAG, "Applying timezone: %s", Config::getTimezone());
  Config::applyTimezone();

  ESP_LOGI(TAG, "Waiting for network connection...");
  vTaskDelay(pdMS_TO_TICKS(5000));

  {
    uint32_t ip = 0;
    bool up = (g_ethernet && g_ethernet->getIpAddr(ip));
#if CONFIG_SOC_WIFI_SUPPORTED
    up = up || (g_wifi && g_wifi->getIpAddr(ip));
#endif
    if (up) cfg_boot_healthy();
  }

  if (Config::getUseDisplay()) {
    ESP_LOGI(TAG, "Initializing display...");
    g_display = new Display(Config::getSpiHost(), Config::getCsPin(), Config::getMaxDevices(), Config::getSpiClockHz());
    err = g_display->begin();
    if (err == ESP_OK) {
      ESP_LOGI(TAG, "Display initialized successfully");
      g_display->setIntensity(1);
      g_displayMutex = xSemaphoreCreateMutex();
      ESP_LOGI(TAG, "Display mutex created");
    } else {
      ESP_LOGE(TAG, "Display init failed: %d", err);
      delete g_display;
      g_display = nullptr;
    }
  } else {
    ESP_LOGI(TAG, "Display disabled via config");
  }

  // GPS/PPS will discipline time; NTP client not required.

  // Start GPS/PPS disciplining
  g_gps = new GpsDiscipline();
  g_gps->begin(Config::getGpsUartPort(), Config::getGpsUartBaud(), Config::getGpsUartTxPin(), Config::getGpsUartRxPin(), Config::getPpsGpioPin());

  // Start NTP server (passes GPS reference for lock checking)
  // Latch W5500 packet arrival on a second MCPWM capture channel, sharing the
  // 80 MHz counter that timestamps PPS. Must come after gps->begin() (which
  // creates the capture timer) and before the server starts using it. Wired
  // (not wireless) only — lwIP buffers datagrams, so there is no edge to latch.
  if (!Config::getNetworkWifi() && Config::getW5500IntPin() >= 0) {
    esp_err_t rxerr = g_gps->beginRxCapture(Config::getW5500IntPin());
    if (rxerr == ESP_OK)
      ESP_LOGI(TAG, "RX arrival capture armed on GPIO%d (shared PPS timebase)",
               Config::getW5500IntPin());
    else
      ESP_LOGW(TAG, "RX arrival capture unavailable (%s); t2 falls back to the "
                    "GPIO ISR stamp", esp_err_to_name(rxerr));
  }

  g_ntpServer = new NtpServer();
  g_ntpServer->begin(Config::getNtpServerPort(), g_gps);
  if (g_ethernet) {
    // A W5500 register loss closes every hardware socket along with
    // everything else -- NTP's and MQTT's alike; reopen/reset them whenever
    // the ethernet layer rebuilds the chip. W5500Eth has a single callback
    // slot, so both owners are notified from this one registration.
    g_ethernet->onChipReset([](void*) {
      if (g_ntpServer) g_ntpServer->reopenSocket();
      if (g_mqtt) MqttPublisher::chipResetTrampoline(g_mqtt);
    }, nullptr);
  }

  g_web = new WebServer();
  g_web->begin(Config::getStatsPort(), g_gps, g_ntpServer, g_ethernet, g_wifi);

  if (Config::getMqttEnable() && Config::getNetworkWiznet() && g_ethernet) {
    g_mqtt = new MqttPublisher();
    esp_err_t mqttErr = g_mqtt->begin(
      Config::getMqttBrokerIp(), Config::getMqttBrokerPort(),
      Config::getMqttUsername(), Config::getMqttPassword(),
      Config::getMqttClientId(), Config::getMqttNodeId(),
      Config::getMqttPublishIntervalS(),
      g_gps, g_ntpServer, g_ethernet);
    if (mqttErr != ESP_OK) {
      ESP_LOGE(TAG, "MQTT publisher init failed: %s", esp_err_to_name(mqttErr));
      delete g_mqtt;
      g_mqtt = nullptr;
    }
  }
  gettimeofday(&tv, nullptr);
  struct tm timeinfo;
  localtime_r(&tv.tv_sec, &timeinfo);
  
  ESP_LOGI(TAG, "Initial time: %02d:%02d:%02d", timeinfo.tm_hour, timeinfo.tm_min, timeinfo.tm_sec);

  if (g_display) {
    vTaskDelay(pdMS_TO_TICKS(50));
    g_display->clear();
    g_display->drawPreSyncGlyph();
    g_display->push();

    ESP_LOGI(TAG, "Starting display task...");
    xTaskCreatePinnedToCore(display_task, "display_task", 4096, nullptr, 4, nullptr, 1);
  }

  ESP_LOGI(TAG, "Entering main loop...");
  /*
   * Split the old single poll loop into prioritised tasks.
   *
   * The monolithic loop ended in vTaskDelay(1), so a packet waited up to a full
   * tick before being answered — that random latency was the dominant term in
   * served jitter, and it also meant an arrival capture could not be reliably
   * paired with the datagram that produced it. Worse, NTP load and GPS
   * disciplining shared one thread, so traffic could starve the clock.
   *
   * Now: discipline runs at the highest priority on its own core, the NTP
   * server blocks on a notification from the INTn ISR (so it wakes on arrival
   * rather than on a timer), and housekeeping runs lowest. Each task registers
   * with the Task Watchdog, which is already configured to panic — a wedged
   * discipline task now reboots the box instead of serving a frozen clock.
   */
  xTaskCreatePinnedToCore(discipline_task, "discipline", 4096, nullptr,
                          PRIO_DISCIPLINE, nullptr, CORE_CLOCK);
  xTaskCreatePinnedToCore(ntp_task, "ntp_srv", 4096, nullptr,
                          PRIO_NTP, nullptr, CORE_NET);
  ESP_LOGI(TAG, "tasks started: discipline(prio %d core %d) ntp(prio %d core %d)",
           PRIO_DISCIPLINE, CORE_CLOCK, PRIO_NTP, CORE_NET);
  /* app_main returns; the tasks own the system from here. */
}

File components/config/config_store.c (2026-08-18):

// SPDX-License-Identifier: Unlicense

#include "config_store.h"
#include "sdkconfig.h"
#include "nvs.h"
#include "nvs_flash.h"
#include "hal/spi_types.h"
#include "esp_log.h"
#include "esp_attr.h"
#include <string.h>
#include <stdio.h>
#include <stdlib.h>

static const char* TAG = "CFGSTORE";
static const char* NVS_NS = "ntpcfg";

/* Kconfig entries that only exist under one branch of the network choice. */
#ifndef CONFIG_APP_USE_PRESYNC_GLYPH
#define CONFIG_APP_USE_PRESYNC_GLYPH 0
#endif
#ifndef CONFIG_APP_WIFI_SSID
#define CONFIG_APP_WIFI_SSID ""
#endif
#ifndef CONFIG_APP_WIFI_PASSWORD
#define CONFIG_APP_WIFI_PASSWORD ""
#endif
#ifndef CONFIG_APP_STATIC_IP_ADDR
#define CONFIG_APP_STATIC_IP_ADDR "192.168.1.100"
#endif
#ifndef CONFIG_APP_STATIC_GW
#define CONFIG_APP_STATIC_GW "192.168.1.1"
#endif
#ifndef CONFIG_APP_STATIC_NETMASK
#define CONFIG_APP_STATIC_NETMASK "255.255.255.0"
#endif
#ifdef CONFIG_APP_NETWORK_WIFI
#define DEF_NET_MODE 1
#else
#define DEF_NET_MODE 0
#endif
#ifdef CONFIG_APP_USE_STATIC_IP
#define DEF_NET_DHCP 0
#else
#define DEF_NET_DHCP 1
#endif
#ifdef CONFIG_APP_USE_DISPLAY
#define DEF_DISP_EN 1
#else
#define DEF_DISP_EN 0
#endif

#define PIN_OUT -1, 33
#define PIN_IN  -1, 39

#ifdef CONFIG_SOC_WIFI_SUPPORTED
static const char* const kNetModes[] = { "wiznet", "wifi" };
#define NET_MODE_MAX 1
#else
static const char* const kNetModes[] = { "wiznet" };
#define NET_MODE_MAX 0
#endif

static const char* const kTzOpts[] = {
  "UTC0",                                    "UTC",
  "GMT0BST,M3.5.0/1,M10.5.0",                "UK - London",
  "CET-1CEST,M3.5.0,M10.5.0/3",              "Central Europe - Paris, Berlin, Madrid",
  "EET-2EEST,M3.5.0/3,M10.5.0/4",            "Eastern Europe - Athens, Helsinki",
  "<-01>1<+00>,M3.5.0/0,M10.5.0/1",          "Azores",
  "NST3:30NDT,M3.2.0,M11.1.0",               "Canada - Newfoundland",
  "AST4ADT,M3.2.0,M11.1.0",                  "Canada - Atlantic",
  "EST5EDT,M3.2.0,M11.1.0",                  "US/Canada - Eastern",
  "CST6CDT,M3.2.0,M11.1.0",                  "US/Canada - Central",
  "MST7MDT,M3.2.0,M11.1.0",                  "US/Canada - Mountain",
  "MST7",                                    "US - Arizona (no DST)",
  "PST8PDT,M3.2.0,M11.1.0",                  "US/Canada - Pacific",
  "AKST9AKDT,M3.2.0,M11.1.0",                "US - Alaska",
  "HST10",                                   "US - Hawaii (no DST)",
  "<-03>3",                                  "Brazil - Sao Paulo",
  "<-03>3",                                  "Argentina - Buenos Aires",
  "<-06>6",                                  "Mexico - Mexico City",
  "MSK-3",                                   "Russia - Moscow",
  "<+04>-4",                                 "Gulf - Dubai",
  "IST-5:30",                                "India",
  "<+07>-7",                                 "Thailand, Vietnam",
  "CST-8",                                   "China, Singapore, Hong Kong",
  "JST-9",                                   "Japan",
  "KST-9",                                   "Korea",
  "AWST-8",                                  "Australia - Perth",
  "ACST-9:30ACDT,M10.1.0,M4.1.0/3",          "Australia - Adelaide",
  "AEST-10AEDT,M10.1.0,M4.1.0/3",            "Australia - Sydney, Melbourne",
  "AEST-10",                                 "Australia - Brisbane (no DST)",
  "NZST-12NZDT,M9.5.0,M4.1.0/3",             "New Zealand",
  "SAST-2",                                  "South Africa",
  NULL
};

#define PIN_HELP "ESP32 GPIO. 34-39 are input-only."
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

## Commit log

2026-08-04 Skip ARP prime for resolved peer, tighten capture gate
    [ntp_server.cpp, w5k_udp_wrapper.c]
2026-08-04 one SPI transaction per W5500 access on the reply path
2026-08-04 run the CPU at 240 MHz, fix truncated /metrics, recalibrate served offset
    [config.cpp, ntp_server.cpp, w5k_udp_wrapper.c]
2026-08-04 put the reply path in IRAM; scope the SPI counters honestly
2026-08-04 Grow dispersion at frequency-estimate uncertainty, not raw error
    [gps.cpp]
2026-08-12 fix timezone kconfig not being read, guard missing display macro
    Two independent bugs found while bringing this project up on new hardware:
    1. getTimezone() returned a hardcoded literal ("AST4ADT,M3.2.0,M11.1.0")
    instead of reading CONFIG_APP_TZ, even though the Kconfig option for it
    already existed. No menuconfig edit could ever change the timezone.
    2. getUseDisplay() referenced CONFIG_APP_USE_DISPLAY unconditionally. When
    the display is disabled in menuconfig, ESP-IDF does not define that
    macro at all (it is simply absent, not defined to 0), so disabling the
    display in menuconfig broke the build. Guarded with #ifdef, defaulting
    to false when the option is compiled out.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
    [config.cpp]
2026-08-12 add 3d-printable enclosure (step + stl, top lid and bottom case)
    * Add 3D-printable enclosure (STEP + STL, top lid and bottom case)
    Two-piece magnet-held case sized for the D1 Mini ESP32 board, W5500
    breakout, and MAX-M10S GPS module used by this project. Designed in
    Fusion 360, sliced/printed with Orca Slicer.
    Both halves have embedded 6x2mm magnet holes (6.2mm diameter, 2.4mm
    depth) to hold the lid closed without screws -- see
    hardware/enclosure/README.md for the exact clearances above each
    magnet cutout.
    * hardware/enclosure: document mounting screws and correct magnet count (4 per half)
    [bottom-case.step, bottom-case.stl, top-lid.step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]
2026-08-12 sync committed sdkconfig with the board: 240 MHz cpu, 80 MHz flash
2026-08-13 Fix ESP-IDF v6.0 build errors: driver component splits, volatile increments, missing-field-initializer, missing <time.h>, close() collision
    ESP-IDF v6.0 reorganized several driver components (GPIO/UART moved out of
    the generic "driver" component into esp_driver_gpio/esp_driver_uart, only
    reachable via PRIV_REQUIRES from within "driver" itself, not passed to
    dependents) and made several previously-cosmetic warnings into hard errors:
    - components/gps, components/w5500_eth: add esp_driver_gpio /
    esp_driver_uart to REQUIRES so driver/gpio.h and driver/uart.h resolve.
    - components/w5500_eth/w5500_eth.cpp: C++20+ deprecates '++'/'+=' on
    volatile-qualified variables (this project builds with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
    [app_main.cpp, w5500_eth.cpp]
2026-08-13 wire ntp server/port kconfig into config.cpp
2026-08-13 document the fail-loud contract over the reply-path spin
    [w5500_eth.cpp]
2026-08-13 wire display spi kconfig into config.cpp, drop dead ntp port getter
2026-08-13 replace the wiznet iolibrary with a first-party w5500 driver and dhcp client
    [app_main.cpp, ntp_server.cpp, w5500_drv.c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]
2026-08-13 store settings in nvs and add a management ui on the stats server
    [partitions.csv]
2026-08-13 fix the boot-fail counter and let the management password be removed
    [app_main.cpp, config_store.c]
2026-08-13 pin every setting on first save so a value matching the build default still persists
2026-08-13 declare 2mb flash so the partition table still fits small esp32 modules
    [partitions.csv]
2026-08-13 declare the real idf floor, 4.1 never had the split driver components
2026-08-13 let the settings page be fused off for good, and say so in the readme
2026-08-13 Re-apply fork-specific docs onto upstream's current main
    - .gitignore: untrack sdkconfig (real local network settings) and
    PLANS.local.md, matching the fork's existing policy
    - README: re-add the "About this fork" section
    - CLAUDE.md: carried over as historical record, with a note at the top
    flagging that upstream rewrote the driver/stats/settings layers this
    document describes fixes for, so most of Parts 2/3/5/6 are history now,
    not a map of the current source
    MQTT component, the ioLibrary_Driver fork, and the old bandaid SPI/tick
    fixes are intentionally not carried over -- MQTT will be re-ported onto
    upstream's new first-party driver separately.
2026-08-14 Re-port MQTT publishing onto upstream's native w5500_drv
    Upstream's rewrite (2b52c9c) replaced the vendored ioLibrary_Driver with a
    first-party w5500_drv, which also fixes the recv() non-blocking-order bug
    natively -- so the forked ioLibrary_Driver submodule this project used to
    carry solely for that fix is no longer needed at all.
    MQTT is re-implemented from scratch as a hand-rolled, zero-dependency MQTT
    3.1.1 wire codec (components/mqtt_publish/mqtt_wire.{h,c}), replacing the
    previous vendored-Paho-based implementation, since Paho was tied to the
    now-dropped ioLibrary_Driver. Same design as before: a non-blocking,
    tick-driven state machine polled from ntp_task's housekeeping slot, at most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
    [app_main.cpp, config.cpp, mqtt_wire.c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]
2026-08-14 Add curated sdkconfig.defaults instead of a full config snapshot
    Addresses JR's PR review feedback directly: don't commit a full
    idf.py save-defconfig dump (it carries local network settings and
    credentials into the repo), list changes one by one instead so each
    can be reviewed on its own.
    Five lines, each justified individually: no display attached, DHCP
    by default (no half-configured static IP), match upstream's -O2
    build (a debug build measurably changes timing on a
    microsecond-precision server -- also flagged in the same review),
    the FreeRTOS tick-rate fix for the real watchdog-reset bug (Part 3,
    CLAUDE.md), and a POSIX-format timezone example.
    Deliberately excludes CPU freq, flash fre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
2026-08-14 README: update fork section for the upstream rewrite
    The two original PR bullets (v6.0.2 build fixes, Kconfig bugs) described
    bugs in code this branch no longer carries -- upstream's own rewrite
    (first-party w5500_drv, NVS-backed settings) fixes both natively. Replaced
    with a note explaining why, plus a bullet crediting upstream's driver for
    fixing the old ioLibrary_Driver recv() bug so the forked submodule and
    patch could both be dropped.
    Also updated the MQTT bullet (hand-rolled zero-dependency codec, not the
    old Paho-derived one) and added a bullet for sdkconfig.defaults.
2026-08-14 default the serve calibration to the measured value
2026-08-15 grow holdover dispersion at the drift rate, not the compensated offset
    [gps.cpp]
2026-08-15 cut the accuracy claims down, document the settings properly
2026-08-18 CLAUDE.md: document the upstream-integration work as Part 7
    Adds the record of what happened after rebasing onto upstream's rewrite:
    why the rebase happened, dropping the forked ioLibrary_Driver, the MQTT
    re-implementation (not a port), the real PR review findings and how they
    were resolved (sdkconfig.defaults instead of a committed snapshot), the
    multi-hour settling-time investigation and what's still open (the no-MQTT
    A/B test), and folding in upstream's subsequent commits before promotion.
    Updates the top disclaimer and current-status blurb to match, and replaces
    the stale pre-rewrite file list with one accurate for this branch (kept
    the old one too, marked historical).
